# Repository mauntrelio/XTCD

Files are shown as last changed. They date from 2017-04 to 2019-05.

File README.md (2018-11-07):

# XTCD

**XFEL Tunnel Camera Drone**

XTCD (XFEL Tunnel Camera Drone) is a project about the design, test and implementation of tunnel inspection battery powered drones moving on rails, controlled with Raspberry Pis via a responsive web interface on the Wi-Fi network connection.

## Folder structure:

- **docs**: documentation
- **installation**: installation scripts and config template files
- **old_stuff**: old scripts and software used during the first development phase
- **scripts**: useful scripts
- **system**: core part of the software, contains the Python scripts to run the web server and operate the drone. This is the part that is going to be installed on the Raspberry Pi.

**TODO**: The content of the **system** folder needs to be documented in detail.

## Dependencies:

- Python libraries:
	- RPiHTTPServer (web server with basic routing, authentication and static file management)
	- Adafruit PCA9685 (PWM board controller on I2C bus)
	- Adafruit ADS1x15 (Analog to digital converter on I2C bus)
	- pystache (html templates)
	- netifaces (network interfaces discovery)

- Other software
	- UV4L (https://www.linux-projects.org/uv4l/) (web streaming of video)
	- watchdog (optional) (restart in case of network problems, cpu overload, high temperature)

## Raspberry Pi configuration:

In order to create a RPi image to run XTCD, please read documentation in  
docs/XTCD - How to create a new image.md

**TODO**: Spefic configuration parameters of `system/config/*.json` files have to be documented yet.

## Contributing:

1. Fork it
2. Create your feature branch (git checkout -b my-new-feature)
3. Commit your changes (git commit -am 'Add some feature')
4. Push to the branch (git push origin my-new-feature)
5. Create new Pull / Merge Request

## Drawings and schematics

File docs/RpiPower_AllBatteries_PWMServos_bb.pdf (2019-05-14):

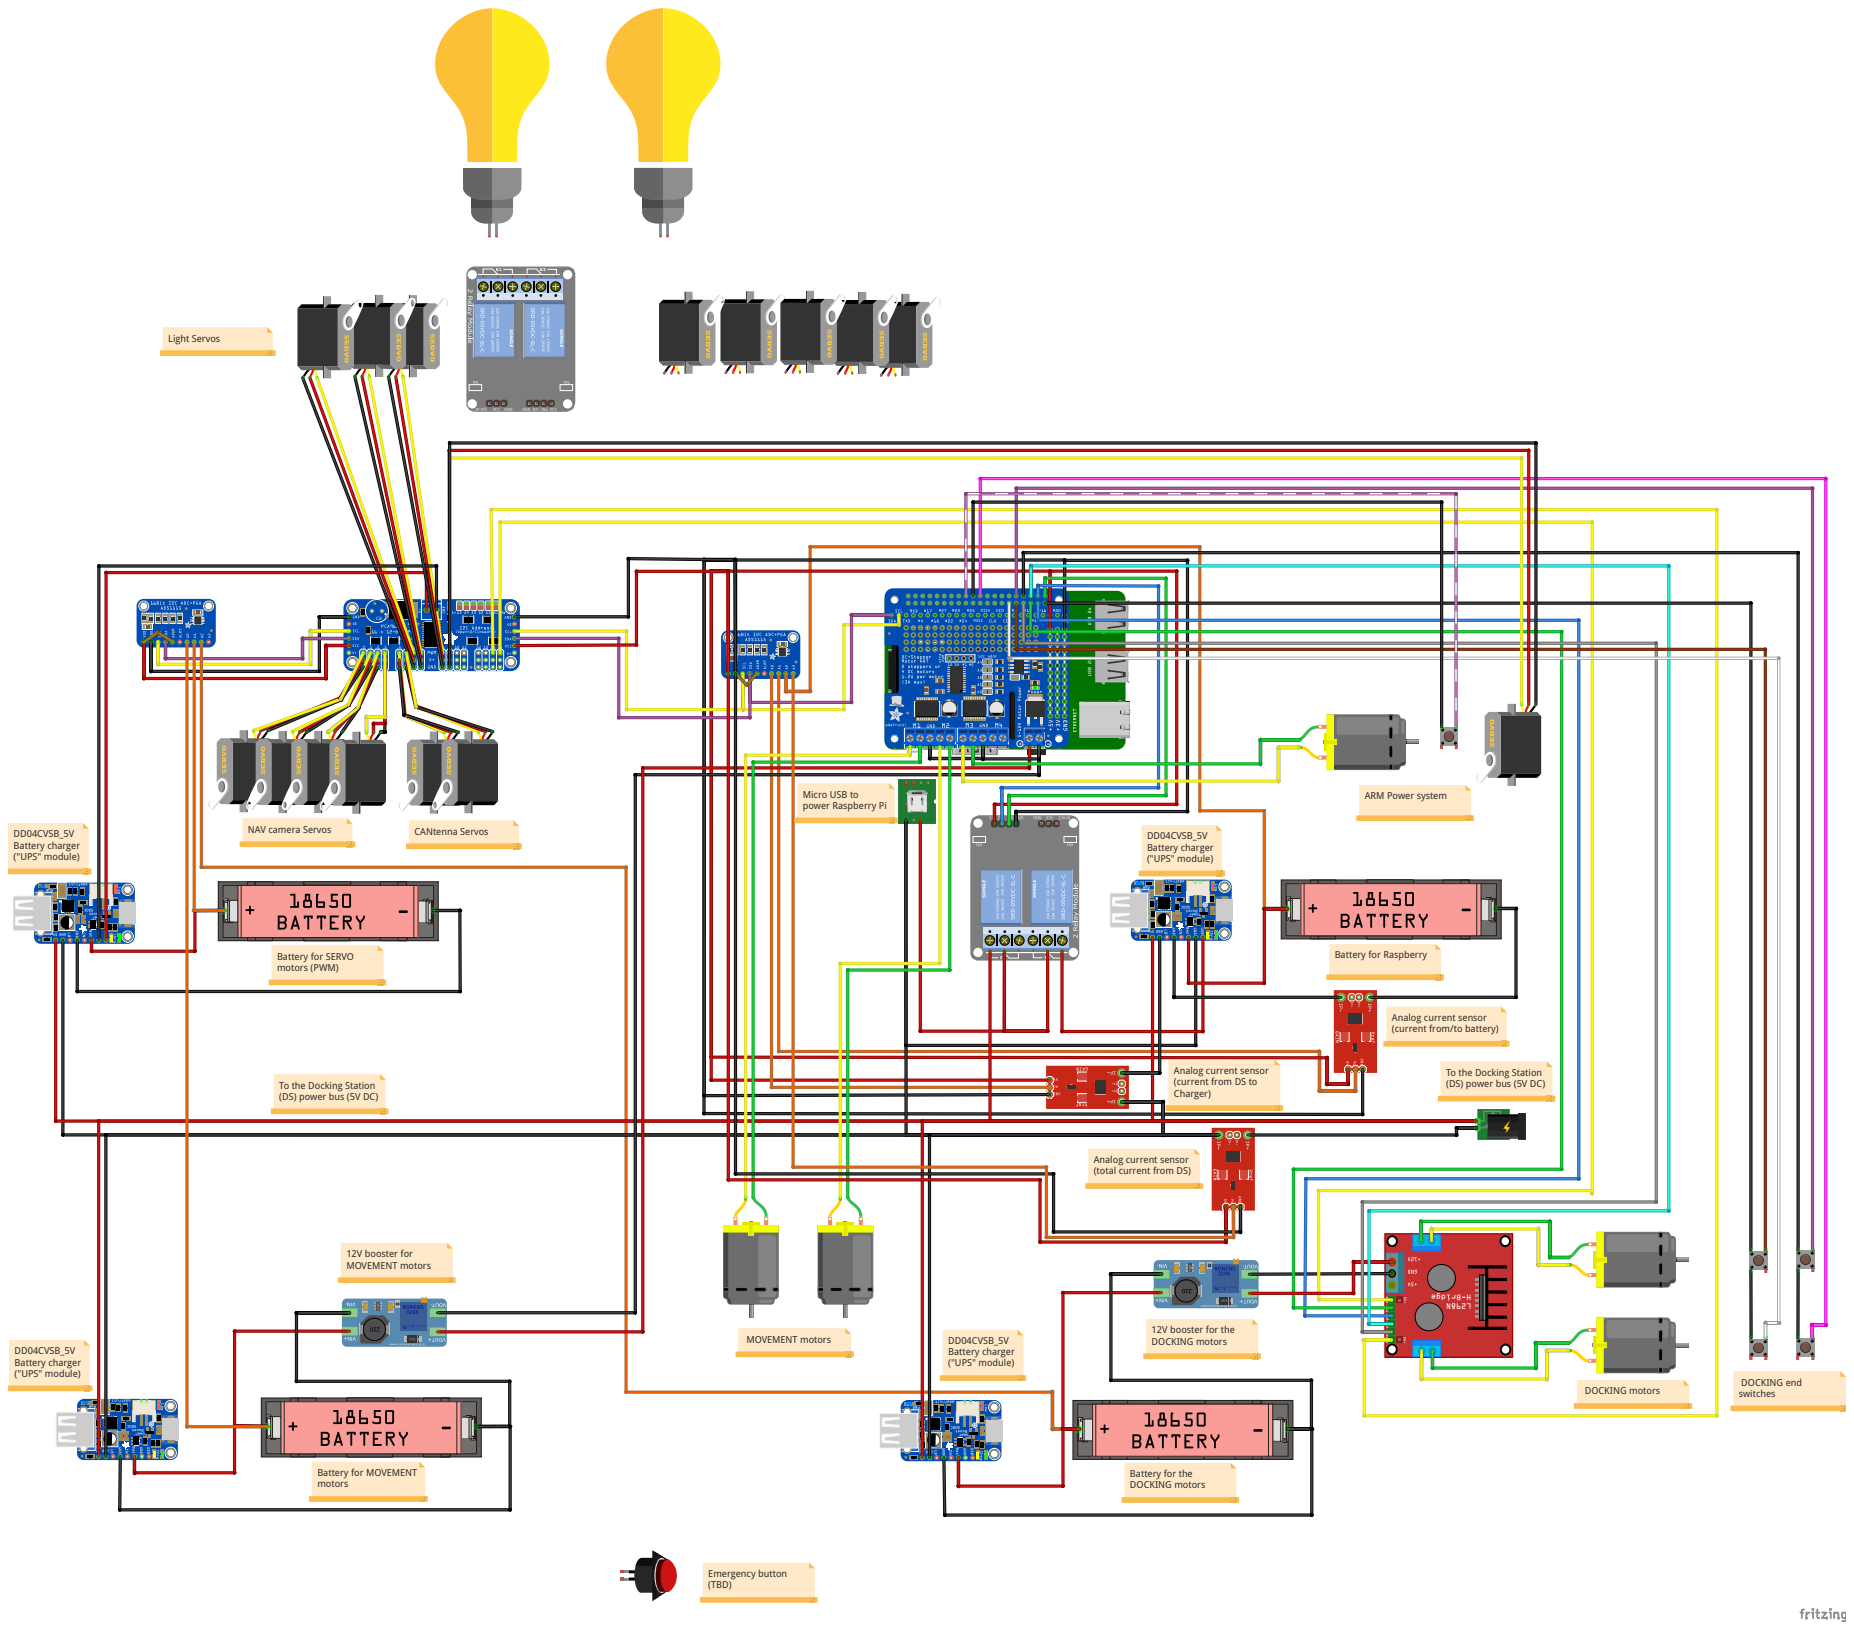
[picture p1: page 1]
To the Dock; (DS) power bus (5V DC) ing Station; DD04CVSB_5V Battery charger ("UPS" module); 12V booster for MOVEMENT motors; DOCKING end; DOCK; switches; ING motors; MOVEMENT motors; DOCKING motors; CANtenna Servos; Light Servos; Emergency button (TBD)

Micro USB to
power Raspberry Pi

ARM Power system

NAV camera Servos

Battery for SERVO
motors (PWM)

Battery for Raspberry

Analog current sensor
(current from/to battery)

(current from DS to
Charger)

To the Docking Station

(DS) power bus (5V DC)

(total current from DS)

12V booster for the

Battery for MOVEMENT
motors

Battery for the
DOCKING motors

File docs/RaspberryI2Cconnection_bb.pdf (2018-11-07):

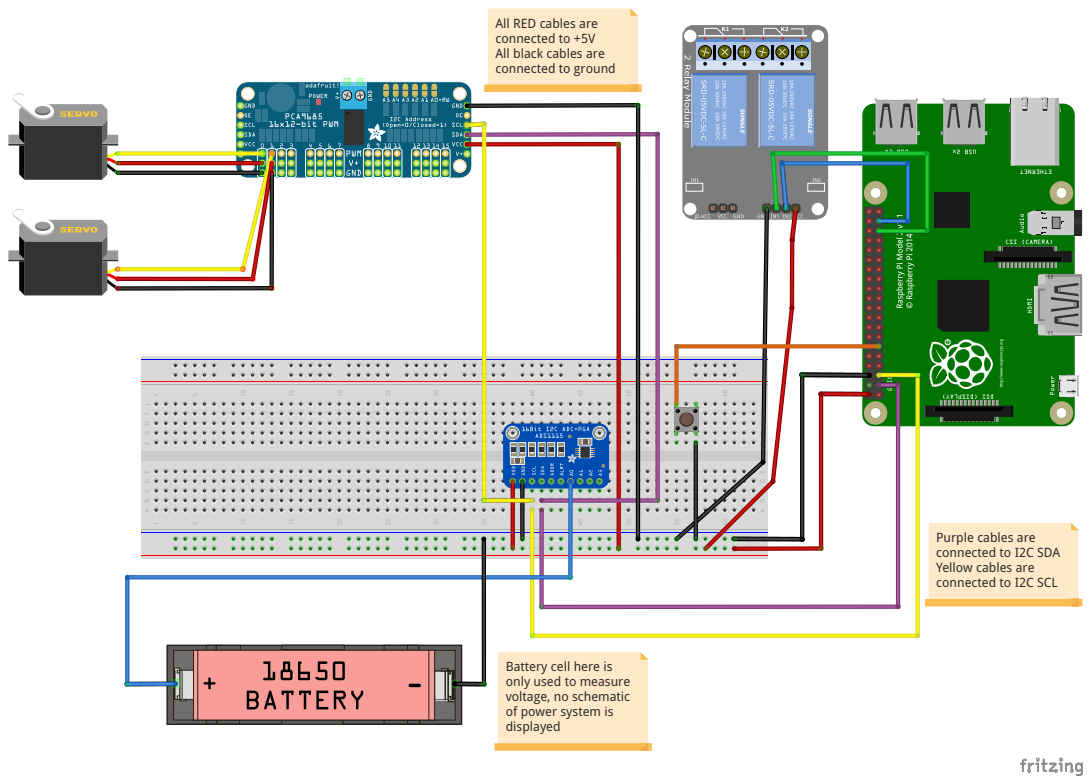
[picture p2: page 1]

All RED cables are
connected to +5V
All black cables are
connected to ground

Purple cables are
connected to I2C SDA
Yellow cables are
connected to I2C SCL

Battery cell here is
only used to measure
voltage, no schematic
of power system is
displayed

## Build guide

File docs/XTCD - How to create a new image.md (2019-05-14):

# XTCD - How to create a new image

Please note the following instructions refer to Raspbian Strecth as of October 2018.

## On a Desktop Ubuntu/Debian PC:

- Download Raspbian lite image from:

```bash
cd /tmp
mkdir -p /tmp/raspi
cd /tmp/raspi
wget https://downloads.raspberrypi.org/raspbian_lite_latest -O raspbian.img.zip
unzip raspbian.img.zip
mv *.img raspbian.img
```

### Mounting the image 

- Mount the image (it's an image of two partion, so you need losetup):

```bash
loopdevice=`losetup -f`
losetup -P $loopdevice raspbian.img
mkdir -p /mnt/raspimg
mount "$loopdevice"p2 /mnt/raspimg
mount "$loopdevice"p1 /mnt/raspimg/boot
```

The previous commands are supposed to be run as root (or with sudo)

### Optional: avoid that the filesystem is immediately resized on boot

- Edit cmdline.txt in boot partition by removing the argument

	`init=/usr/lib/raspi-config/init_resize.sh`

- Also remove the file

	`/mnt/raspimg/etc/init.d/resize2fs_once`

	and the symbolic link to it

	`/mnt/raspimg/etc/rc3.d/S01resize2fs_once`

### Setting up the Wi-Fi connection 

Copy `installation/config_resources/desy.pem` certificate into `/mnt/raspimg/etc/ca-certificates/`

Copy `installation/config_resources/wpa-supplicant.conf` into `/mnt/raspimg/etc/wpa-supplicant/`

Change the copied `wpa-supplicant.conf` in order to set up the correct passwords.

### Changing hostname

Edit hostname in `/mnt/raspimg/etc/hostname`

### Changing the root (and pi) password

Create a password for user pi using 

	mkpasswd -m sha-512 <newpassword> <salt> 

The salt value is a random string of your choice, anything will do.

Change the `/mnt/raspimg/etc/shadow` file with the new password above. Delete the string between the 1st and 2nd ‘:’ colons on the line starting with "root" (and "pi"). Paste in the new value between these colons.

### Activate SSH and set up ssh-keys

Place an empty file named 'ssh' onto the boot (FAT) partition

	touch /mnt/raspimg/boot/ssh

Put the content of your public key(s) in `/mnt/raspimg/root/.ssh/authorized_keys`

### Activate modules

Content of `/mnt/raspimg/boot/config.txt`

	dtparam=i2c_arm=on
	dtparam=spi=on
	enable_uart=1
	dtoverlay=w1-gpio

	# enable camera
	start_x=1
	gpu_mem=128

Content of `/etc/modules`

	i2c-dev
	cuse
	bcm2835_wdt

### Set up localization (keyboard and timezone)

Content of `/mnt/raspimg/etc/timezone`

	Europe/Berlin

Content of `/mnt/raspimg/etc/default/keyboard`

	XKBLAYOUT="us"

### Copy the installation script

The following command is referred to the current directory (XTCD/docs)
	
	cp ../installation/install_script.sh /mnt/raspimg/root/
	chmod a+x /mnt/raspimg/root/install_script.sh

### Create the SD card

**IMPORTANT**: replace /dev/sdX in the following command with whatever is your sd card

```bash
umount /mnt/raspimg/boot
umount /mnt/raspimg
losetup -d $loopdevice
dd if=/tmp/raspi/raspbian.img of=/dev/sdX bs=4M conv=fsync status=progress
```

----------------------------------------------------------------------------

## On the Raspberry	

Put the SD card in and boot the system up.

Log in as root, make sure the system is connected to the network, then run the install script:

	/mnt/raspimg/root/install_script.sh

The software is installed into `/var/XTCD`

After installation, adjust the config *.json files in `/var/XTCD/system/config` as needed.

Reboot.

Point your browser on the web address of the Raspberry Pi:

	http://raspberry-ip-address:service-port/

Enjoy!

-----------------------------------------------------------------------------

## Troubleshooting

If the service does not start (e.g. not reachable via web browser) do the following:

- Go to /var/XTCD/system
- Manually launch the script main.py and check the output

Be sure that the PWM board is **connected and powered** (this hardware component is needed for the system to start).

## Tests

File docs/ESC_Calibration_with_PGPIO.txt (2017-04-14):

ESC Calibration with PGPIO

http://abyz.co.uk/rpi/pigpio/

import pigpio

# Connect to pigpio
pi = pigpio.pi() 

# Calibrate ESC
ESC_GPIO = 13
pi.set_servo_pulsewidth(ESC_GPIO, 2000) # Maximum throttle.
sleep(2)
pi.set_servo_pulsewidth(ESC_GPIO, 1000) # Minimum throttle.
sleep(2)

# Left shift speed then OR by negated pin value
speed = (speed << 1) | (1 ^ GPIO.input(pin))

# Set ESC speed via PWM
pi.set_servo_pulsewidth(ESC_GPIO, speed * 1000 / 7 + 1000)

pi.set_servo_pulsewidth(ESC_GPIO, 0) # Stop servo pulses.
pi.stop() # Disconnect pigpio.

WARNING:  the ESC will retain calibration until it is disconnected from the power supply.  If you run the above calibration code on an ESC that has already been calibrated, the motor will spin up to high speed for 2 seconds.  Please note that calibration is required for the ESC to operate

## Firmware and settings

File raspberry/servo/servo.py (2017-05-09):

#!/usr/bin/python
# -*- coding: utf-8 -*-
from RPiHTTPServer import RPiHTTPServer, RPiHTTPRequestHandler
import Adafruit_PCA9685
import os
import time
import re

class ServoHandler(RPiHTTPRequestHandler):

  # GET /
  def default_response(self):
    tpl_vars = {
      '{{message}}': '',
      '{{selected000}}': '',
      '{{selected090}}': '',
      '{{selected180}}': ''
    }

    """Control servo according to QS param"""
    if 'pos' in self.qs:
      pos = self.qs['pos'][0]
      # only if param is one of the possible values
      if pos in self.server.positions.keys():
        # send data to pwm controller
        pwm_set = self.server.positions[pos]
        self.server.pwm.set_pwm(self.server.config.SERVO_CHANNEL, 0, pwm_set)
        self.server.pwm.set_pwm(self.server.config.SERVO_CHANNEL+1, 0, pwm_set)
        self.server.pwm.set_pwm(self.server.config.SERVO_CHANNEL+2, 0, pwm_set)
        # self.server.pwm.set_all_pwm(0, pwm_set)
        # set template vars for GUI
        tpl_vars['{{message}}'] = "Setting PWM to %s" % pwm_set
        tpl_vars["{{selected%s}}" % pos] = "selected"

    print tpl_vars['{{message}}']

    # render templates
    self.render_template(tpl_vars)

  def render_template(self, tpl_vars):
    tpl = os.path.join(self.server.root_folder, 'home.html')
    tpl_content = open(tpl,"r").read()
    pattern = re.compile('|'.join(tpl_vars.keys()))
    self.content = pattern.sub(lambda x: tpl_vars[x.group()], tpl_content)


def main():

  # read configuration from json
  basedir = os.path.dirname(os.path.abspath(__file__))
  config_file = os.path.join(basedir,"config.json")

  # instantiate http server
  SwitchServer = RPiHTTPServer(config_file, ServoHandler)

  # quick access to config params
  config = SwitchServer.server.config

  # instantiate and initialise pwm controller
  pwm = Adafruit_PCA9685.PCA9685(address=int(config.I2C_ADDR,16))
  pwm.set_pwm_freq(config.SERVO_FREQ)
  positions = {
    "000": config.SERVO_MIN,
    "090": (config.SERVO_MAX + config.SERVO_MIN)/2,
    "180": config.SERVO_MAX
  }


  # assign variables to server
  SwitchServer.server.pwm = pwm
  SwitchServer.server.positions = positions
  SwitchServer.server.root_folder = basedir

  try:
    print "Server listening on http://%s:%s" % (config.SERVER_ADDRESS,config.SERVER_PORT)
    SwitchServer.serve_forever()
  except KeyboardInterrupt:
    pass
    SwitchServer.server.server_close()


if __name__ == '__main__':

  main()

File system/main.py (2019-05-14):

#!/usr/bin/python
# -*- coding: utf-8 -*-

from RPiHTTPServer import RPiHTTPServer
from drone import Drone
from sensors import Sensors
from web import WebHandler
from collections import OrderedDict
import threading
import time
import os
import sys
import json
import traceback
import atexit
import signal
import logging
from logging.handlers import RotatingFileHandler
from logging import handlers

# class coordinating the components:
# - web server
# - drone controller
# - sensors controller

class XTCD:

  def __init__(self, basedir):
    web_config_file = os.path.join(basedir,"config","web.json")
    drone_config_file = os.path.join(basedir,"config","drone.json")
    sensors_config_file = os.path.join(basedir,"config","sensors.json")

    # be sure to give exception immediately if web config is missing or malformed
    self.web_config = json.load(open(web_config_file,'r'), object_pairs_hook=OrderedDict)
    # instantiate http server
    self.web = RPiHTTPServer(web_config_file, WebHandler)
    
    # setup logging
    self.setup_logger(basedir)

    # parse drone config file and instantiate drone controller
    self.drone_config = {}
    if os.path.isfile(drone_config_file):
      try:
        self.drone_config = json.load(open(drone_config_file,'r'), object_pairs_hook=OrderedDict)
        self.log("Instantiating drone controller", severity = 20)
        self.drone = Drone(self.drone_config, controller = self)
      except Exception as e:
        self.log("Error in drone configuration", severity = 40)
        self.log(traceback.format_exc(), severity = 40)

    # parse sensors config file and instantiate sensors controller
    self.sensors_config = {}
    if os.path.isfile(sensors_config_file):
      try:
        self.sensors_config = json.load(open(sensors_config_file,'r'), object_pairs_hook=OrderedDict)
        self.log("Instantiating sensors controller", severity = 20)
        self.sensors = Sensors(self.sensors_config, controller = self) 
      except Exception as e:
        self.log("Error in sensors configuration", severity = 40)
        self.log(traceback.format_exc(), severity = 40)

    # pass data to web server
    self.web.server.controller = self
    self.web.server.root_folder = basedir
    self.web.server.web_config_file = web_config_file
    self.web.server.drone_config_file = drone_config_file  
    self.web.server.sensors_config_file = sensors_config_file

  # setup the logger
  def setup_logger(self, basedir):
    # configure logging
    log_file = os.path.join(basedir,"logs","xtcd.log")
    if "LOG_LEVEL" in self.web_config:
      log_level = self.web_config["LOG_LEVEL"]
    else:
      log_level = 40
    
    logger = logging.getLogger()
    logger.setLevel(log_level)
    log_format = logging.Formatter('[%(asctime)s] - %(name)s/%(threadName)s - %(levelname)s - %(message)s')

    log_ch = logging.StreamHandler(sys.stdout)
    log_ch.setFormatter(log_format)
    logger.addHandler(log_ch)

    log_fh = handlers.RotatingFileHandler(log_file, maxBytes=(1048576*5), backupCount=7)
    log_fh.setFormatter(log_format)
    logger.addHandler(log_fh)

  # start xtcd
  def start(self):
    # start the keep alive thread if needed
    if "KEEP_ALIVE" in self.drone_config:
      self.log("Starting keep alive thread", severity = 20)
      self.drone.keep_alive(self.drone_config["KEEP_ALIVE"]["MIN"])
    self.log("Starting web server on http://%s:%s" % (self.web_config["SERVER_ADDRESS"],self.web_config["SERVER_PORT"]), severity = 20)
    self.web.serve_forever()

  # stop xtcd 
  def stop(self):
    # stop the drone
    self.log("Exiting: stopping drone", severity = 30)
    self.drone.shutdown()
    # stop the web server
    self.log("Exiting: stopping web server", severity = 30)
    self.web.server.server_close()

  # logger
  def log(self, message, severity = 10):
    logging.log(severity, message)

if __name__ == '__main__':

  basedir = os.path.dirname(os.path.abspath(__file__))
  xtcd = XTCD(basedir)

  # exit properly stopping motors, web server, etc..
  def handle_exit(*args):
    try:
      xtcd.stop()
    except:
      pass
      
  # register exit function
  atexit.register(handle_exit)
  signal.signal(signal.SIGTERM, handle_exit)
  signal.signal(signal.SIGINT, handle_exit)

  try:
    xtcd.start()
  except KeyboardInterrupt:
    xtcd.stop()

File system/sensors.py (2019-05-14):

#!/usr/bin/python
# -*- coding: utf-8 -*-

import Adafruit_ADS1x15
import time
import subprocess
import traceback

class Sensors:
  def __init__(self, config, controller=None):

    self.config = config

    self.status = {}
    for key in self.config.keys():
      self.status[key] = {
        "id": key,
        "value": None,
        "reading": None,
        "unit": self.config[key]["unit"]
      }

    # ADC (TODO: put gain in the configuration, either global, or per sensor)
    self.adc = Adafruit_ADS1x15.ADS1115()
    self.adc_GAIN = 2/3
    self.adc_MAX_VAL = 4.096*3/2
    self.adc_MAX = 32768.0

    self.controller = controller

  # TODO:
  #   - implement periodic readings (interval)
  #   - implement Data Logger
  #   - implement different methods get_value (to get the last read value for periodic readings) 
  #     and read_value (to read a value immediately)

  def get_sensor(self, sensor_id):
    if not sensor_id in self.status:
      self.controller.log("Sensor %s not found" % sensor_id)
      return {
        "id": sensor_id,
        "value": None,
        "reading": None,
        "unit": ""
      }

    sensor = self.status[sensor_id]  

    # read the sensor if we do not have a value
    if not sensor["value"]:
      self.controller.log("Reading sensor %s because value is missing" % sensor_id)
      self.read_sensor(sensor_id)

    # read the sensor if last reading is older then it should be
    if time.time() - sensor["reading"] > self.config[sensor_id]["frequency"]:
      self.controller.log("Reading sensor %s because cached value is expired" % sensor_id)
      self.read_sensor(sensor_id)

    # return the sensor
    return self.status[sensor_id] 


  def read_sensor(self, sensor_id):

    value = None

    if not sensor_id in self.config:
      return {
        "id": sensor_id,
        "value": None,
        "reading": None,
        "unit": ""
      }

    sensor = self.config[sensor_id]
    source = sensor["source"]
    params = sensor["source_params"]

    try:
      # command line sensor
      if source == "commandline":
        value = subprocess.check_output(params["cmd"], shell=True)

      # ADS1 sensor
      elif sensor["source"] == "ADS1":
        reading = self.adc.read_adc(params["channel"], gain=self.adc_GAIN)
        value = (reading / self.adc_MAX) * self.adc_MAX_VAL

      # DHT sensor
      elif sensor["source"] == "DHT":
        types = {'11': Adafruit_DHT.DHT11,
                  '22': Adafruit_DHT.DHT22,
                  '2302': Adafruit_DHT.AM2302 }
        
        if params["type"] in types:
          sensor_type = types[params["type"]]
          h, t = Adafruit_DHT.read_retry(sensor_type, params["pin"])
          if params["index"] == 0:
            value = h
          else:
            value = t
        
      # BMP sensor
      elif sensor["source"] == "BMP":
        if hasattr(self.bmp, params["method"]):
          value = getattr(self.bmp, params["method"])()
          value *= params["multiplier"]

    except Exception as e:
      self.controller.log("Error reading sensor %s" % sensor_id, severity = 40)
      self.controller.log(traceback.format_exc(), severity = 40)
      value = None  

    if sensor["type"] == "float":
      if value:
        value = float(value)
        value = round(value,2)

    self.status[sensor_id]["value"] = value
    # update time of last reading
    self.status[sensor_id]["reading"] = time.time()

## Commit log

2017-03-31 Initial commit of XFEL tunnel drone camera control
2017-04-04 Using PWM board to control servomotors
2017-04-18 Re-organized Raspberry code. Brushless motor procedures. Started web interface to PCA9685
2017-04-21 Added static assets (bootstrap and jquery). Added stub class. Fixed configuration.
    [main.py]
2017-04-25 Add proper Adafruit library to web PCA9685 interface. Configurable I2C addrress in servos
2017-05-09 Drone control web interface initial prototype
2017-05-13 Remove web_PCA9685. Fixed start procedure in XTCD
    [main.py]
2017-05-16 Updated last changes after real testing on railsù
2017-05-16 Fix bug, rearrange template
    [main.py]
2017-05-16 Use real PCA9685. Re-assign stop keyboard shortcut
    [drone.py]
2017-06-02 Add code to control brush motors
2017-06-06 Brush motors adjustments + relay switches
2017-06-06 Relay switches controlled from PWM board
2017-06-08 Fix servo for brush motors
    [drone.py]
2017-06-08 Fixed problems with switch and brush motor, changed direction of arrows in interfacea
    [drone.py]
2017-06-09 Add script keep_alive to avoid PWM power bank going off. Fixed bug in setting speed when motor is stopped
    [drone.py]
2017-06-14 Keep alive mechanism on a spare servo
2017-07-06 Implement proper keep_alive with threads
2017-07-17 Failsafe mechanism for ip address evaluation
    [main.py]
2017-07-20 Adding generic primitives to control pwm from web interface directly
2017-07-21 Add three APIs to control PWM directly from web interface (TODO: improve consistency of PWM channel statuses)
2018-08-21 Basic sensors implementation
2018-08-22 General improvements to sensors
2018-08-22 Yet improvements to sensors
2018-11-07 Add Raspberry I2C Connection diagram
    [RaspberryI2Cconnection.fzz]
2019-01-08 Split web functionalities in a separate module. Improved sensors module
2019-01-10 Fixed sensors and improved error logging
    [main.py, sensors.py]
2019-01-11 Implementation of DC Motor controlled by ESC
2019-01-12 Implemented DC motors ESC controller in a separate class
2019-01-12 Implemented class for DC motor controlled via Stepper HAT
2019-01-12 Implementing class to control L298N controlled DC motor
2019-01-13 Fixing bugs on DC motors dirvers. Setting up a setup with all kind of motors
    [drone.py, web.py]
2019-01-13 Manage DC operations in different threads. Add ID information to motor logging
2019-01-13 Parametrize motors in web commands
2019-01-14 Fix configuration parsing error
    [web.py]
2019-01-14 Re-organized DC Motors drivers in a packeage
2019-01-14 Fixed error in save configuration
    [main.py]
2019-01-14 Fix GPIO handling. Improve error messages in logfile
    [drone.py, main.py, sensors.py]
2019-01-14 Make stopping motor message log consistent
2019-01-14 Stop motors and cleanup hardware at exit
2019-05-14 Update documentation with general loop device instructions
2019-05-14 Adding latest schematics
    [RpiPower_AllBatteries_PWMServos.fzz]
2019-05-14 Add script to enable connection from masked Raspberry Pi when developing at the workstation
2019-06-09 Avoid reverse DNS lookup in loggining
    [web.py]
2019-07-16 New Wi-Fi configuration for DESY and eduroam Wi-Fi. Additional USB Wi-Fi adapters drivers install script
